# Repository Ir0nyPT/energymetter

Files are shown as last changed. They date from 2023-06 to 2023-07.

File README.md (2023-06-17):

# energymetter
contador de energia

# Pre-requesitos
1. Gerar chave no computador para pedir acesso ao github. Após correr o comando, este irá perguntar o ficheiro onde guardar e pass a atribuir, clicar no "Enter" 3 vezes para avançar sem adicionar qualquer valor
> ssh-keygen -t rsa -b 4096

2. Imprimir no terminal a chave gerada
> cat ~/.ssh/id_rsa.pub 

3. Ir ao link abaixo e colar a chave imprimida no último comando no espaço "Key" (chave completa e sem qualquer alteração). Como Título é indiferente o que escreves
https://github.com/settings/ssh/new

4. Clonar o repositório
> git clone git@github.com:Ir0nyPT/energymetter.git

5. Instalar e inicializar 
> cd energymetter

> ./script.sh setup

> ./script.sh init

# Compilar e descarregar
> ./script.sh buildandcopy

OU 

> ./script.sh build

> ./script.sh copy

# Comando disponíveis no script

## Inicializar
> ./script.sh init

## Compilar
> ./script.sh build

## Apagar cache - util para recompilar
> ./script.sh clean

## Enviar para o Pico
> ./script.sh copy

## Obter um terminal de "Debug" (com a ferramenta Minicom)
### Iniciar terminal
> ./script.sh debug
### Terminar terminal
> Press CTRL+A X
### Dar comando para o rasp ir para modo de programação
Com o terminal de debug aberto escrever "reboot" e pressionar enter

# Como guardar algerações?
Antes de iniciar alguma alteração do programa cria um "ramo" do programa
> git checkout -b devop_mj

Após alterações feitas, para reter as alterações
> git add .

Para gravar as alterações. Alterar a "mensagem" por uma breve descrição do que fizes-te
> git commit -m "mensagem"

Para enviar para o github de forma a partilhar
> git push -u origin devop_mj

# Como atualizar com as alterações online?
Desta forma iras obter alterações que outros tenham feito
> git pull 

# Pico W LED
https://github.com/raspberrypi/pico-examples/blob/master/pico_w/wifi/blink/picow_blink.c

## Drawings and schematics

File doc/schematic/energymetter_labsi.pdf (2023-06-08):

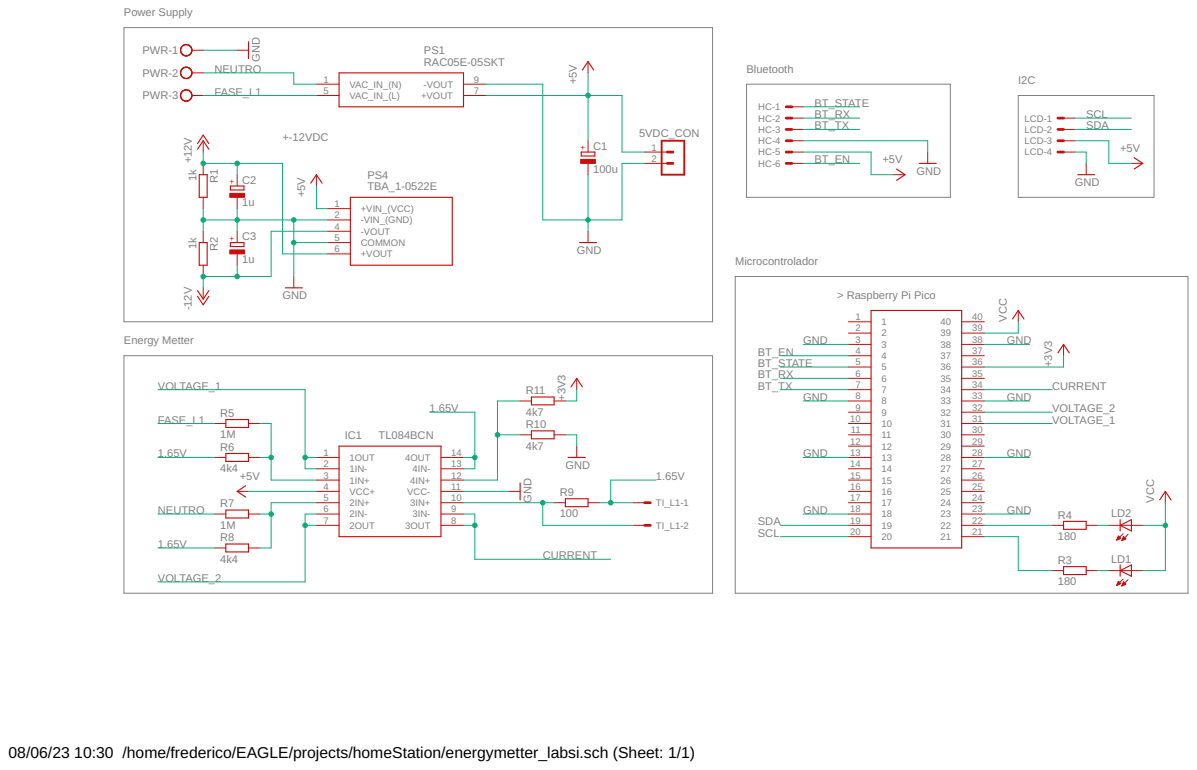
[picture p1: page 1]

Bluetooth

08/06/23 10:30 /home/frederico/EAGLE/projects/homeStation/energymetter_labsi.sch (Sheet: 1/1)

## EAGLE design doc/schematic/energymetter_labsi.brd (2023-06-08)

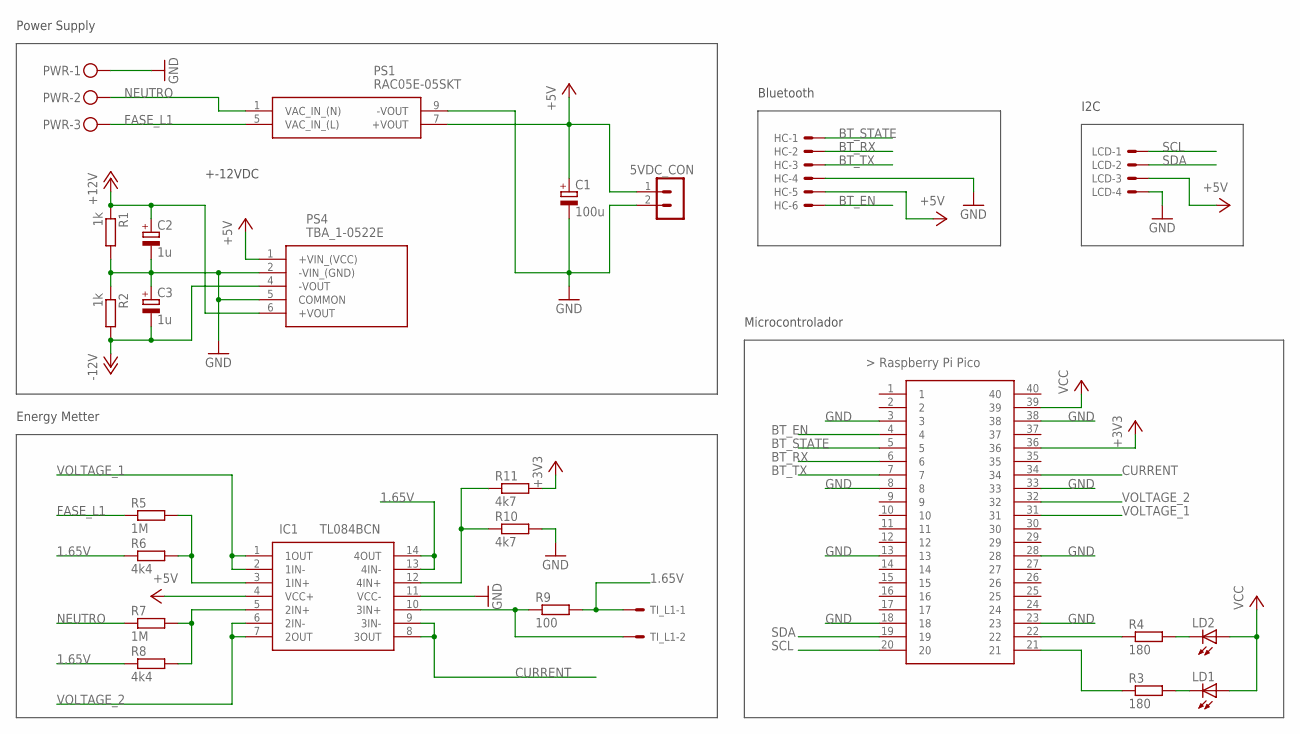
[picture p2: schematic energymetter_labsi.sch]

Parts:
5VDC_CON: MA02-1
C1: 100u; E2-5
C2, C3: 1u; E2-5
HC: 22-23-2061
IC1: TL084BCN; DIP794W53P254L1930H508Q14N
LCD: Display; 22-23-2041
LD1, LD2: LED5MM
PS1: RAC05E-05SKT; RAC05E05SKT
PS4: TBA_1-0522E; TBA10522E
PWR: MKDSN1,5/3-5,08
R1, R2: 1k; 0204/7
R3, R4: 180; 0204/7
R5, R7: 1M; 0204/7
R6, R8: 4k4; 0204/7
R9: 100; 0204/7
R10, R11: 4k7; 0204/7
TI_L1: 22-23-2021
U$1: RASPBERRY-PI-PICO_TH; FT_RASPBERRY-PI-PICO_TH

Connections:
1.65V: IC1.13 (4IN-), IC1.14 (4OUT), R6.1, R8.1, R9.2, TI_L1.1
+3V3: R11.2, U$1.36
+5V: 5VDC_CON.1 (2), C1.+, HC.5, IC1.4 (VCC+), LCD.3, PS1.7 (+VOUT), PS4.1 (+VIN_(VCC))
+12V: C2.+, PS4.6 (+VOUT), R1.1
-12V: C3.-, PS4.4 (-VOUT), R2.2
BT_EN: HC.6, U$1.4
BT_RX: HC.2, U$1.6
BT_STATE: HC.1, U$1.5
BT_TX: HC.3, U$1.7
CURRENT: IC1.8 (3OUT), IC1.9 (3IN-), U$1.34
FASE_L1: PS1.5 (VAC_IN_(L)), PWR.3, R5.1
GND: 5VDC_CON.2 (3), C1.-, C2.-, C3.+, HC.4, IC1.11 (VCC-), LCD.4, PS1.9 (-VOUT), PS4.2 (-VIN_(GND)), PS4.5 (COMMON), PWR.1, R1.2, R2.1, R10.2, U$1.3, U$1.8, U$1.13, U$1.18, U$1.23, U$1.28, U$1.33, U$1.38
unnamed: R4.1, U$1.22
unnamed: R3.1, U$1.21
unnamed: LD1.K (C), R3.2
unnamed: LD2.K (C), R4.2
unnamed: IC1.10 (3IN+), R9.1, TI_L1.2
unnamed: IC1.3 (1IN+), R5.2, R6.2
unnamed: IC1.5 (2IN+), R7.2, R8.2
unnamed: IC1.12 (4IN+), R10.1, R11.1
NEUTRO: PS1.1 (VAC_IN_(N)), PWR.2, R7.1
SCL: LCD.1, U$1.20
SDA: LCD.2, U$1.19
VCC: LD1.A, LD2.A, U$1.39
VOLTAGE_1: IC1.1 (1OUT), IC1.2 (1IN-), U$1.31
VOLTAGE_2: IC1.6 (2IN-), IC1.7 (2OUT), U$1.32

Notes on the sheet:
Power Supply
+-12VDC
Microcontrolador
Bluetooth
I2C
Energy Metter

Board: 2 copper layers, 25 parts (0 on the bottom side), 26 nets, no tracks yet.

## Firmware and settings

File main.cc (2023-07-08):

#include "hardware/adc.h"
#include "hardware/gpio.h"
#include "hardware/timer.h"  //library for timer
#include "pico.h"
#include "pico/multicore.h"
#include "pico/stdio.h"
#include "pico/stdlib.h"
#include "pico/time.h"
#include "pin_defines.h"
#include <stdio.h>

#include "lib/core1.h"
#include "lib/energymetter.h"

#define timer_sync_us 200
#define timer_sync_us_adjust -3

volatile bool flag_timer{false};

static bool timer_IRQ(struct repeating_timer* t)
{
    /* Flag Timer */
    flag_timer = true;

    return true;
}

void init()
{
    /* Initialise I/O */
    stdio_init_all();

    /* Status PIN */
    gpio_init(pin_led_1Hz);
    gpio_set_dir(pin_led_1Hz, 1);

    /* Timer Interrupt */
    static struct repeating_timer timerClock;
    add_repeating_timer_us(timer_sync_us + timer_sync_us_adjust, timer_IRQ, NULL, &timerClock);

    /* Initialise Second core with Serial in Scan*/
    multicore_launch_core1(serialInput);

    /* Inicializar módulo WIFI */
    // cyw43_arch_init();
}

int main()
{
    init();

    energymetter contador_energia;

    bool led_state = false;
    uint16_t cnt = 0;

    while (1)
    {
        /* Trigger pelo timer (200 us) */
        if (flag_timer)
        {
            /* Analisa Energia */
            contador_energia.Update();

            /* Led 1 Hz (500 ms) */
            if (cnt >= 2500)
            {
                gpio_put(pin_led_1Hz, led_state);  // so aqui altera o estado
                led_state = !led_state;            // guarda so o estado
                cnt = 0;
            }
            else
            {
                cnt++;
            }

            flag_timer = false;
        }

        /* Serial */
        if (multicore_fifo_rvalid())
        {
            uint32_t cmd = multicore_fifo_pop_blocking();

            switch (cmd)
            {
                case 'v':
                    multicore_fifo_push_blocking(static_cast<uint32_t>(contador_energia.GetVoltage_RMS() * 10.0f));
                    break;
                case 'f':
                    multicore_fifo_push_blocking(static_cast<uint32_t>(contador_energia.GetFrequency()));
                    break;

                default:
                    break;
            }
        }
    }

    return 0;
}

/* TEMPERATURA

INIT:
    adc_gpio_init(30);  // INICIALIZAÇAO COMO ANALOGICO TEMP
    adc_set_temp_sensor_enabled(1);  // ENABLE TEMPERATURE

Run:
    adc_select_input(4);  // SELECÇÃO DO ADC A LER;
    float temp_voltage = 3.3f * adc_read() / (1 << 12);

    float temperatura = 27 - (temp_voltage - 0.706) / 0.001721;
*/

/*
DESAFIO 1:

- c, c++ mostrar fazer programas
- algoritmo recebe corrente e tensao e de-me potencia ao longo
- pensar aplicação resistencias em parelo, serie,
- manual da aplicação - fluxograma


DESAFIO 2

- programa tipo ler entrada do microcontrolador
- potenciometro no micro; (LER DOCS, CODIGO EXEMPLO)
- Timers;
- adc;
- interrupt;


DESAFIO 3

- perceber o prjecto/ fluxograma/ passos a usar .....
- pensar como se faze muito burro;
- achar v max , por tempo;
- achar i max, por tempo;
- calcular potencia....
- integrar como fazer no micro....
(SOMATORIO AO LONGO DO TEMPO);

- DESAFIO
- DUVIDAS
- DEBATE

*/

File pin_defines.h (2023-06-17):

/* Led Requisito Minimo */
#define pin_led_1Hz 18

/* Led Funcionamento */

/* Analógicos - Tensão e Corrente */
#define pin_adc_Fase 26
#define pin_adc_Neutro 27
#define pin_adc_Corrente 28

/* Auxiliar */
#define INPUT 0
#define OUTPUT 1

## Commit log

2023-04-08 Commit inicial - Adição do Pico-SDK como submodulo - Adição de um pequeno programa de base - Adição da opção de poder colocar o micro em modo programação via Serial
2023-06-08 Adição da pasta documentação
    - Adição do esquema em eagle
    [energymetter_labsi.brd, energymetter_labsi.sch]
2023-06-08 - Obter valores de tensão; - Obter valores de temperatura; - Comunicação entre dois cores;
2023-06-17 Leitura de Tensão
    -Limpesa do programa
    -Criação da class para energymetter
    -Leitura de Tensão Fase e Neutro a funcionar
    -Inicio de calculo de frequencia/periodo
2023-07-08 Adição do interrupt timer - Update do contador de energia num periodo conhecido - Led 1 Hz com o interrupt timer
